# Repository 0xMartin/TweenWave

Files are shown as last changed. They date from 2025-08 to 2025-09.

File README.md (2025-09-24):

# TweenWave 🔌📡
#### GPIO Wi‑Fi + Sub‑GHz Module for Flipper Zero








A compact GPIO add‑on for Flipper Zero that combines 2.4 GHz Wi‑Fi and 433 MHz Sub‑GHz into one small board. Perfect for lab experiments, RF tinkering, and extending Flipper’s connectivity.

<table>
    <tr>
        <td align="center" width="50%">
            Real photo of TweenWave<br/>
            <sub>Actual TweenWave module (real photo)</sub>
        </td>
        <td align="center" width="50%">
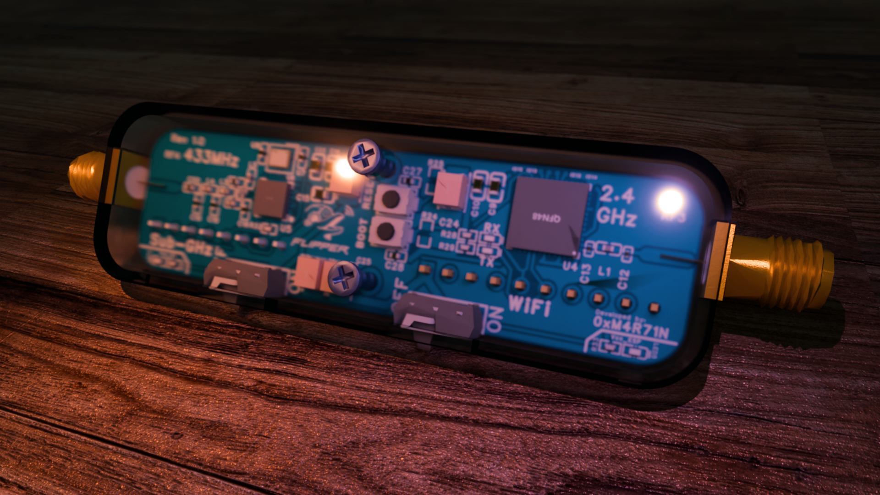
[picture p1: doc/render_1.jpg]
Render of TweenWave
            <br/>
            <sub>3D render of TweenWave (not a real photo)</sub>
        </td>
    </tr>
</table>

The module is designed to be as compact as possible, with replaceable antennas and the ability to remain permanently installed in the port.  
Two micro switches allow you to activate or deactivate the Wi‑Fi and Sub‑GHz radios, preventing unnecessary power draw when not in use.

> Photo of the TweenWave module plugged directly into the Flipper Zero GPIO port.  

Real photo of TweenWave<br/>

> **ℹ️ NOTE ℹ️** 
>
> Gerber files, Bill of Materials (BOM), and Pick and Place data for manufacturing the GPIO Wi‑Fi + Sub‑GHz Module for Flipper Zero are located in the [./export](./export) directory of this repository.

---

## Highlights

- 🧩 Direct plug‑in to Flipper Zero GPIO
- 📶 Wi‑Fi 2.4 GHz via ESP32‑PICO‑V3‑02  
    - Compatible with ESP32 Marauder firmware
- 📻 Sub‑GHz 433 MHz via TI CC1101
- 📡 External antennas using 2× SMA female connectors (one for Wi‑Fi, one for 433 MHz)
- 🧱 Small footprint, careful RF layout
- 🔄 ESP32 firmware updatable over UART (USB‑TTL)

---

## Specifications

- Radios
    - Wi‑Fi: 2.4 GHz (ESP32‑PICO‑V3‑02)
    - Sub‑GHz: 433 MHz (TI CC1101)
- Antennas: 2× SMA female (Wi‑Fi + 433 MHz)
- Power: from Flipper GPIO (3V3, GND)
- Interfaces
    - ESP32: UART/Serial from Flipper GPIO (for control/logs), flashing via external USB‑TTL
    - CC1101: SPI bus (see schematic)
- Indicators: status/power LEDs as routed on PCB
- Compatibility: Flipper Zero with GPIO header

Note: exact pin mapping and signals are shown in the schematic below.

---

## Quick Start

1. Attach suitable antennas:
     - 2.4 GHz antenna to the Wi‑Fi SMA
     - 433 MHz antenna to the Sub‑GHz SMA
2. Plug the module onto GPIO
3. Enable the Wi‑Fi or Sub‑GHz power switch on the module
4. Use Flipper’s serial/terminal to interact with ESP32 or integrate the CC1101 into your Sub‑GHz workflows

---

## ESP32 Marauder (short guide)

The firmware for this module is located in the `Firmware` directory of this repository. It is a fixed version of Marauder 1.8.6, modified to compile and upload for the ESP32-PICO-V3-02 chip used in this device. The project uses PlatformIO for building and flashing.

Precompiled `.bin` files are available in the repository releases as `MARAUDER_v1.8.6_ESP32_PICO_V3_02.zip`. The release contains:
- `bootloader.bin`
- `firmware.bin`
- `firmware.elf`
- `partitions.bin`

### Flashing precompiled binaries

1. Connect your ESP32-PICO-V3-02 module via USB-TTL to your computer.
2. Use [esptool.py](https://github.com/espressif/esptool) or similar tool to flash the binaries:
    ```sh
    esptool.py --chip esp32 --port /dev/ttyUSB0 --baud 460800 write_flash -z 0x1000 bootloader.bin 0x8000 partitions.bin 0x10000 firmware.bin
    ```
    Adjust the serial port as needed.

### Building and flashing with PlatformIO

1. Install [PlatformIO](https://platformio.org/) (VS Code extension or CLI).
2. Open the `Firmware` folder in PlatformIO.
3. Select the correct environment for ESP32-PICO-V3-02.
4. Click "Build" to compile the firmware.
5. Click "Upload" to flash directly to the chip.

For more details, see the PlatformIO documentation or the Marauder firmware README.

---

## Technical Views

<p align="center">
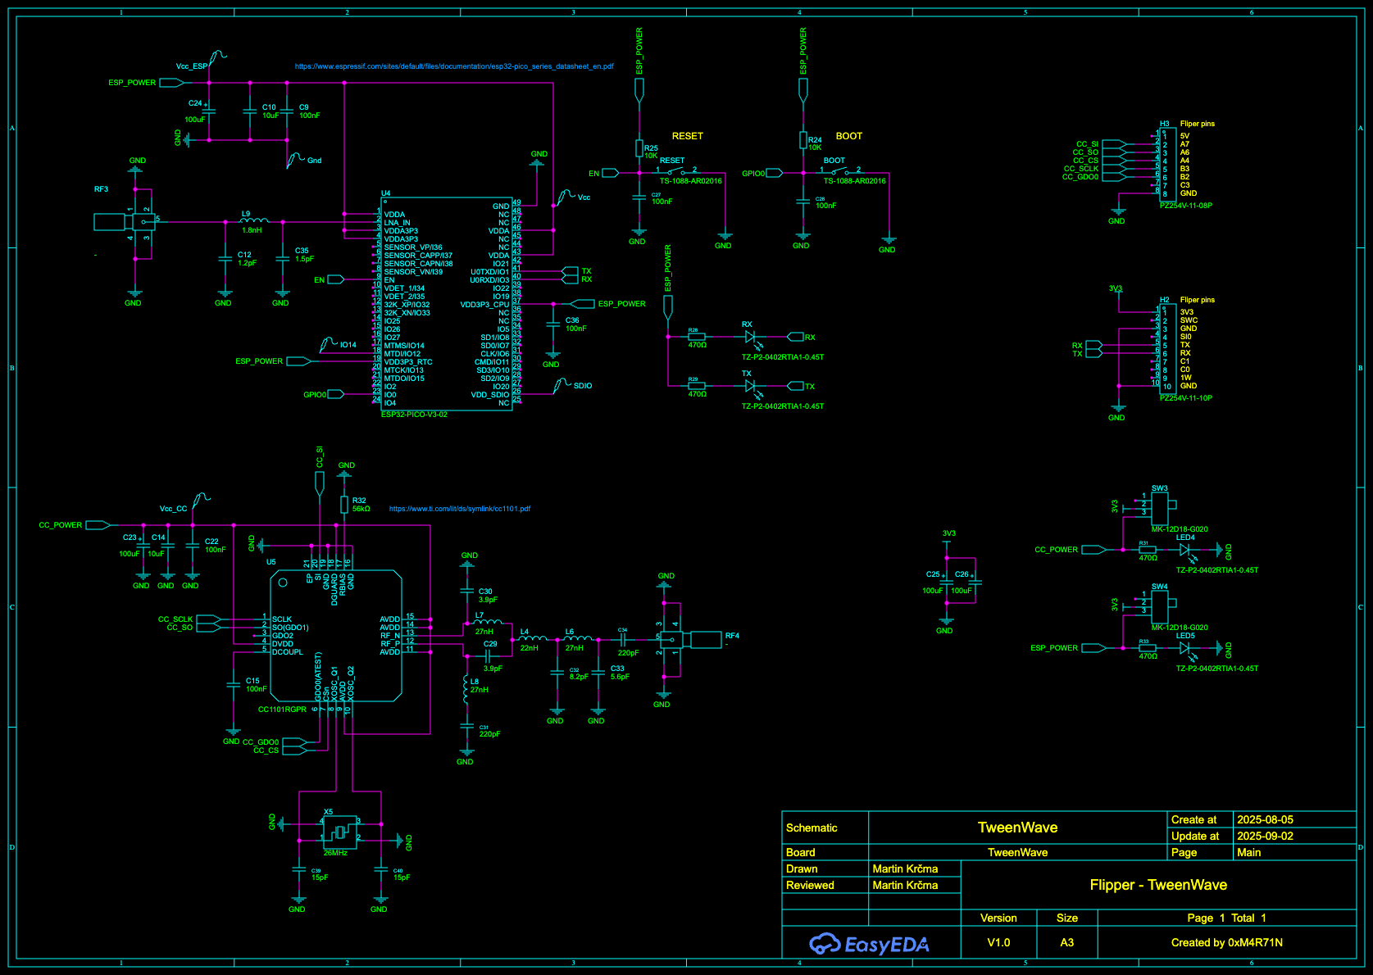
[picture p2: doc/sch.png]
Schematic
    
</p>

<p align="center">
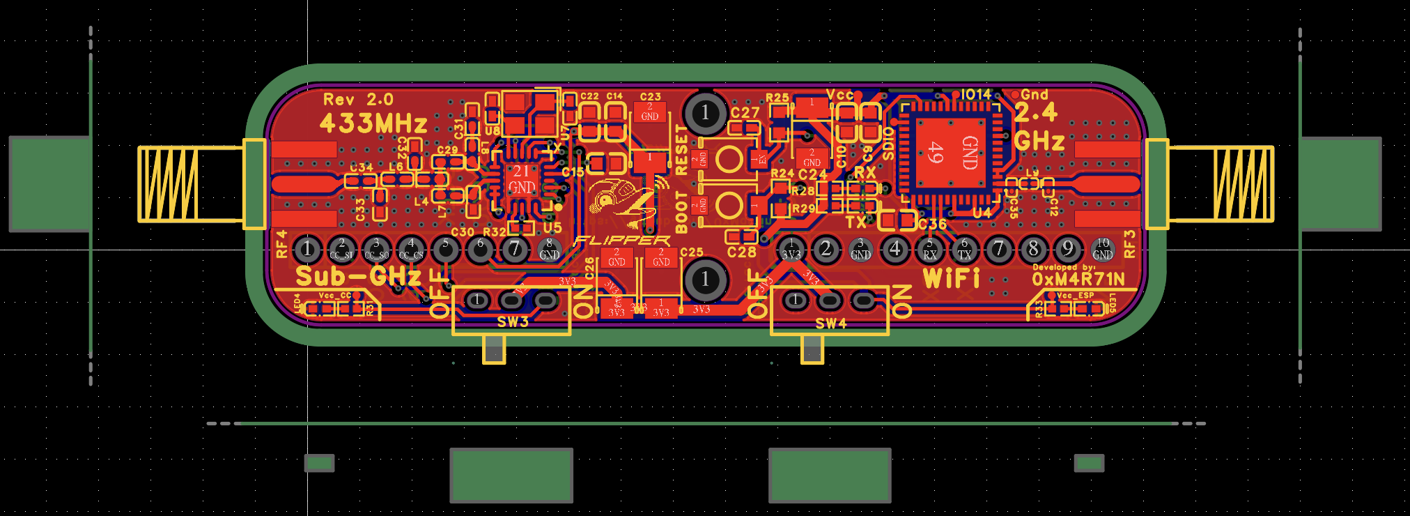
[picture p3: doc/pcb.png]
PCB – top view
    
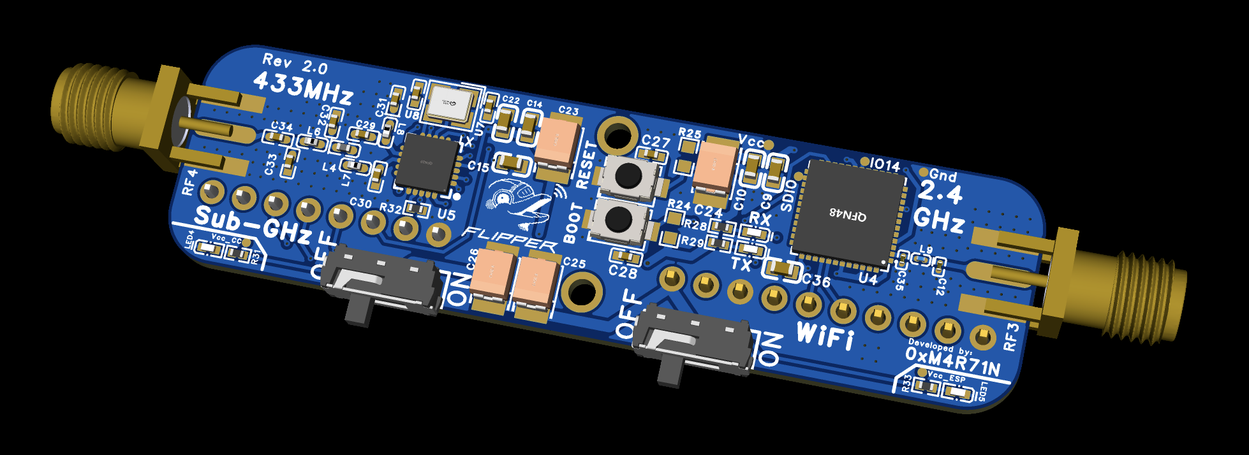
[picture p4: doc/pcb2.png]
PCB – 3D/side view
    
</p>

---

## RF, Safety, and Compliance

- Use properly tuned antennas for 2.4 GHz and 433 MHz.
- Do not transmit without an antenna connected to avoid RF stage damage.
- Observe local regulations and duty‑cycle/ERP limits for ISM bands.
- Regulatory status: not certified. For lab/experimental use only. User is responsible for legal compliance and safe operation.
- Do not use in life‑support, safety‑critical, or mission‑critical systems.

---

## FAQ

- Does it support Marauder?  
    Yes. The ESP32‑PICO‑V3‑02 is wired for ESP32 Marauder support.

- Is CC1101 fixed to 433 MHz only?  
    The design and matching are optimized for 433 MHz. CC1101 can target other sub‑GHz bands, but follow the schematic/matching network and your local regulations.

- Where is the pinout?  
    See the schematic (doc/sch.png).

---

## Part list

| Comment | Designator | Footprint | JLCPCB Part # |
|---|---|---|---|
| 15pF | C39, C40 | C0402 | C106997 |
| 8.2pF | C32 | C0402 | C327205 |
| 56kΩ | R32 | R0402 | C25796 |
| TS-1088-AR02016 | BOOT, RESET | SW-SMD_L3.9-W3.0-P4.45 | C720477 |
| 220pF | C31, C34 | C0402 | C107001 |
| 22nH | L4 | L0402 | C12670 |
| 10K | R24, R25 | R0603 | C137819 |
| 26MHz | X5 | CRYSTAL-SMD_4P-L3.2-W2.5-BL | C15192 |
| 1.2pF | C12 | C0201 | C85895 |
| 100uF | C23, C24, C25, C26 | CASE-B_3528 | C16133 |
| 1.5pF | C35 | C0201 | C161414 |
| - | RF3, RF4 | SMA-SMD_BWSMA-KE-P001 | C496550 |
| 470Ω | R28, R29, R31, R33 | R0402 | C25117 |
| 5.6pF | C33 | C0402 | C505468 |
| 27nH | L6, L7, L8 | L0402-RD | C12669 |
| 100nF | C9, C15, C22, C36 | C0603 | C14663 |
| CC1101RGPR | U5 | QFN-20_L4.0-W4.0-P0.5-TL-EP | C29953 |
| 100nF | C27, C28 | C0402 | C60474 |
| ESP32-PICO-V3-02 | U4 | QFN-48_L7.0-W7.0-P0.50-BL-EP5.1  | C908392 |
| MK-12D18-G020 | SW3, SW4 | SW-TH_MK-12D18-G040 | C3019727 |
| 10uF | C10, C14 | C0603 | C85713 |
| 1.8nH | L9 | L0201-RD | C98040 |
| 3.9pF | C29, C30 | C0402 | C1566 |
| TZ-P2-0402RTIA1-0.45T | LED4, LED5, RX, TX | LED0402-RD_RED | C779449 |

## Author

- 0xM4R71N

---

## License and Disclaimer

Summary (non‑binding): personal, non‑commercial use only; no warranty; you are responsible for safe use and legal compliance.

Legal terms:

- License (Non‑Commercial, Personal, Attribution)
    - Copyright (c) 2025 Martin Krčma (0xM4R71N)
    - Permission is granted to use, view, and modify the hardware design files for personal, experimental, and non‑commercial purposes only.
    - Commercial manufacturing, distribution, or sale of the hardware, derivatives, or prebuilt devices is prohibited without prior written consent from the author.
    - When redistributing modified files for personal/non‑commercial use, retain this notice and attribute “0xM4R71N”.
- Warranty Disclaimer
    - The design, files, and documentation are provided “AS IS”, without warranties or conditions of any kind, express or implied, including but not limited to merchantability, fitness for a particular purpose, and non‑infringement.
- Limitation of Liability
    - To the maximum extent permitted by law, in no event shall the author or contributors be liable for any direct, indirect, incidental, special, exemplary, or consequential damages (including, but not limited to, loss of use, data, business, or profits; personal injury; property damage; or regulatory penalties) arising from or related to the use, misuse, or inability to use this design, even if advised of the possibility of such damages.
- User Responsibility and Compliance
    - You are solely responsible for evaluation, safe assembly, testing, operation, and compliance with applicable laws, regulations, and standards (including RF spectrum use and EMC).
    - Not intended for life‑support, safety‑critical, or high‑risk environments.
- Miscellaneous
    - This notice is not legal advice. For commercial licensing or special permissions, contact the author.
    - Trademarks (e.g., “Flipper Zero”, “ESP32”) belong to their respective owners and are used for identification only.

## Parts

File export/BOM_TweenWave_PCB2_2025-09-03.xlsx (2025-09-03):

No. | Quantity | Comment | Designator | Footprint | Value | Manufacturer Part | Manufacturer | Supplier Part | Supplier
1 | 2 | TS-1088-AR02016 | BOOT,RESET | SW-SMD_L3.9-W3.0-P4.45 |  | TS-1088-AR02016 | XUNPU(讯普) | C720477 | LCSC
2 | 4 | 100nF | C9,C15,C22,C36 | C0603 | 100nF | CC0603KRX7R9BB104 | YAGEO(国巨) | C14663 | LCSC
3 | 2 | 10uF | C10,C14 | C0603 | 10uF | CL10A106MP8NNNC | SAMSUNG(三星) | C85713 | LCSC
4 | 1 | 1.2pF | C12 | C0201 | 1.2pF | GRM0335C1H1R2BA01D | muRata(村田) | C85895 | LCSC
5 | 4 | 100uF | C23,C24,C25,C26 | CASE-B_3528 | 100uF | TAJB107K006RNJ | Kyocera AVX | C16133 | LCSC
6 | 2 | 100nF | C27,C28 | C0402 | 100nF | CC0402KRX7R7BB104 | YAGEO(国巨) | C60474 | LCSC
7 | 2 | 3.9pF | C29,C30 | C0402 | 3.9pF | 0402CG3R9C500NT | FH(风华) | C1566 | LCSC
8 | 2 | 220pF | C31,C34 | C0402 | 220pF | CC0402JRNPO9BN221 | YAGEO(国巨) | C107001 | LCSC
9 | 1 | 8.2pF | C32 | C0402 | 8.2pF | CC0402BRNPO9BN8R2 | YAGEO(国巨) | C327205 | LCSC
10 | 1 | 5.6pF | C33 | C0402 | 5.6pF | CC0402BRNPO9BN5R6 | YAGEO(国巨) | C505468 | LCSC
11 | 1 | 1.5pF | C35 | C0201 | 1.5pF | GRM0335C1H1R5BA01D | muRata(村田) | C161414 | LCSC
12 | 2 | 15pF | C39,C40 | C0402 | 15pF | CC0402JRNPO9BN150 | YAGEO(国巨) | C106997 | LCSC
13 | 6 | Test-Point | Gnd,IO14,SDIO,Vcc,Vcc_CC,Vcc_ESP | Test-Point-0.5mm
14 | 1 | PZ254V-11-10P | H2 | HDR-TH_10P-P2.54-V-M |  | PZ254V-11-10P | XFCN(兴飞) | C492409 | LCSC
15 | 1 | PZ254V-11-08P | H3 | HDR-TH_8P-P2.54-V-M |  | PZ254V-11-08P | XFCN(兴飞) | C492407 | LCSC
16 | 1 | 22nH | L4 | L0402 | 22nH | LQG15HS22NJ02D | muRata(村田) | C12670 | LCSC
17 | 3 | 27nH | L6,L7,L8 | L0402-RD | 27nH | LQG15HS27NJ02D | muRata(村田) | C12669 | LCSC
18 | 1 | 1.8nH | L9 | L0201-RD | 1.8nH | LQP03TN1N8B02D | muRata(村田) | C98040 | LCSC
19 | 4 | TZ-P2-0402RTIA1-0.45T | LED4,LED5,RX,TX | LED0402-RD_RED |  | TZ-P2-0402RTIA1-0.45T | TUOZHAN(拓展光电) | C779449 | LCSC
20 | 2 | 10K | R24,R25 | R0603 |  | RC0603DR-0710KL | YAGEO(国巨) | C137819 | LCSC
21 | 4 | 470Ω | R28,R29,R31,R33 | R0402 | 470Ω | 0402WGF4700TCE | UNI-ROYAL(厚声) | C25117 | LCSC
22 | 1 | 56kΩ | R32 | R0402 | 56kΩ | 0402WGF5602TCE | UNI-ROYAL(厚声) | C25796 | LCSC
23 | 2 | - | RF3,RF4 | SMA-SMD_BWSMA-KE-P001 | - | BWSMA-KE-P001 | BAT WIRELESS(蝙蝠无线) | C496550 | LCSC
24 | 2 | MK-12D18-G020 | SW3,SW4 | SW-TH_MK-12D18-G040 |  | MK-12D18-G020 | G-Switch(品赞) | C3019727 | LCSC
25 | 1 | ESP32-PICO-V3-02 | U4 | QFN-48_L7.0-W7.0-P0.50-BL-EP5.1 |  | ESP32-PICO-V3-02 | ESPRESSIF(乐鑫) | C908392 | LCSC
26 | 1 | CC1101RGPR | U5 | QFN-20_L4.0-W4.0-P0.5-TL-EP |  | CC1101RGPR | TI(德州仪器) | C29953 | LCSC
27 | 1 | 26MHz | X5 | CRYSTAL-SMD_4P-L3.2-W2.5-BL | 26MHz | X322526MMB4SI | YXC(扬兴晶振) | C15192 | LCSC

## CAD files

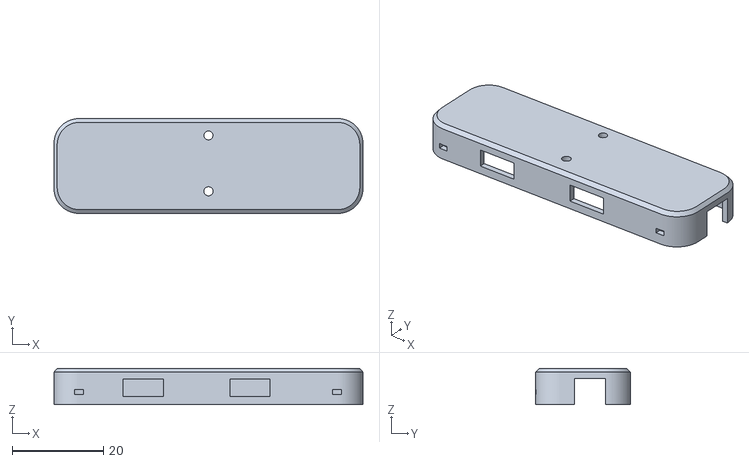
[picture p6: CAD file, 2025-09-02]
case/3DShell_3DShell_PCB2_T.stl
67.7 x 20.8 x 7.97

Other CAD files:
case/tween_wave.blend

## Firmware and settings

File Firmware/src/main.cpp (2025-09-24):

#include "configs.h"

#ifndef HAS_SCREEN
#define MenuFunctions_h
#define Display_h
#endif

#include "EvilPortal.h"
#include "esp_system.h"
#include "esp_wifi.h"
#include "esp_wifi_types.h"
#include "freertos/FreeRTOS.h"
#include "freertos/task.h"
#include <Arduino.h>
#include <WiFi.h>
#include <Wire.h>
#include <stdio.h>

#include "Assets.h"
#include "WiFiScan.h"
#include "Buffer.h"

#include "CommandLine.h"
#include "settings.h"

WiFiScan wifi_scan_obj;
EvilPortal evil_portal_obj;
Buffer buffer_obj;
Settings settings_obj;
CommandLine cli_obj;

const String PROGMEM version_number = MARAUDER_VERSION;

uint32_t currentTime = 0;

void setup()
{
#ifndef HAS_DUAL_BAND
    esp_spiram_init();
#endif

    Serial.begin(115200);

    while (!Serial)
        delay(10);

    Serial.println("ESP-IDF version is: " + String(esp_get_idf_version()));

    settings_obj.begin();
    buffer_obj = Buffer();

    wifi_scan_obj.RunSetup();
    evil_portal_obj.setup();
    wifi_scan_obj.StartScan(WIFI_SCAN_OFF);

    Serial.println(F("CLI Ready"));
    cli_obj.RunSetup();
}

void loop()
{
    currentTime = millis();
    bool mini = false;

    // Update all of our objects
    cli_obj.main(currentTime);
    wifi_scan_obj.main(currentTime);

    // Save buffer to SD and/or serial
    buffer_obj.save();
    settings_obj.main(currentTime);

    delay(50);
}

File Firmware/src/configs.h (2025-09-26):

#ifndef configs_h
#define configs_h

#define POLISH_POTATO

//// BOARD TARGETS
// #define MARAUDER_M5STICKC
// #define MARAUDER_M5STICKCP2
// #define MARAUDER_MINI
// #define MARAUDER_V4
// #define MARAUDER_V6
// #define MARAUDER_V6_1
// #define MARAUDER_V7
// #define MARAUDER_V7_1
// #define MARAUDER_KIT
#define GENERIC_ESP32
// #define MARAUDER_FLIPPER
// #define MARAUDER_MULTIBOARD_S3
// #define ESP32_LDDB
// #define MARAUDER_DEV_BOARD_PRO
// #define XIAO_ESP32_S3
// #define MARAUDER_REV_FEATHER
// #define MARAUDER_CYD_MICRO // 2432S028
// #define MARAUDER_CYD_2USB // Another 2432S028 but it has tWo UsBs OoOoOoO
// #define MARAUDER_CYD_GUITION // ESP32-2432S024 GUITION
// #define MARAUDER_C5
// #define MARAUDER_CARDPUTER
//// END BOARD TARGETS

#define MARAUDER_VERSION "v1.8.6"

#define GRAPH_REFRESH 100

#define DUAL_BAND_CHANNELS 51

#define HAS_PSRAM

//// HARDWARE NAMES
#ifdef MARAUDER_M5STICKC
#define HARDWARE_NAME "M5Stick-C Plus"
#elif defined(MARAUDER_M5STICKCP2)
#define HARDWARE_NAME "M5Stick-C Plus2"
#elif defined(MARAUDER_CARDPUTER)
#define HARDWARE_NAME "M5 Cardputer"
#elif defined(MARAUDER_MINI)
#define HARDWARE_NAME "Marauder Mini"
#elif defined(MARAUDER_V7)
#define HARDWARE_NAME "Marauder v7"
#elif defined(MARAUDER_V7_1)
#define HARDWARE_NAME "Marauder v7.1"
#elif defined(MARAUDER_REV_FEATHER)
#define HARDWARE_NAME "Adafruit Feather ESP32-S2 Reverse TFT"
#elif defined(MARAUDER_V4)
#define HARDWARE_NAME "Marauder v4"
#elif defined(MARAUDER_V6)
#define HARDWARE_NAME "Marauder v6"
#elif defined(MARAUDER_V6_1)
#define HARDWARE_NAME "Marauder v6.1"
#elif defined(MARAUDER_CYD_MICRO)
#define HARDWARE_NAME "CYD 2432S028"
#elif defined(MARAUDER_CYD_2USB)
#define HARDWARE_NAME "CYD 2432S028 2USB"
#elif defined(MARAUDER_CYD_GUITION)
#define HARDWARE_NAME "CYD 2432S024 GUITION"
#elif defined(MARAUDER_KIT)
#define HARDWARE_NAME "Marauder Kit"
#elif defined(MARAUDER_FLIPPER)
#define HARDWARE_NAME "Flipper Zero Dev Board"
#elif defined(MARAUDER_MULTIBOARD_S3)
#define HARDWARE_NAME "Flipper Zero Multi Board S3"
#elif defined(ESP32_LDDB)
#define HARDWARE_NAME "ESP32 LDDB"
#elif defined(MARAUDER_DEV_BOARD_PRO)
#define HARDWARE_NAME "Flipper Zero Dev Board Pro"
#elif defined(XIAO_ESP32_S3)
#define HARDWARE_NAME "XIAO ESP32 S3"
#elif defined(MARAUDER_C5)
#define HARDWARE_NAME "ESP32-C5 DevKit"
#else
#define HARDWARE_NAME "ESP32"
#endif

//// END HARDWARE NAMES

//// BOARD FEATURES
#if defined(MARAUDER_M5STICKC) || defined(MARAUDER_M5STICKCP2)
// #define FLIPPER_ZERO_HAT
#define HAS_MINI_KB
#define HAS_BATTERY
#define HAS_BT
#define HAS_BUTTONS
// #define HAS_NEOPIXEL_LED
#define HAS_PWR_MGMT
#define HAS_SCREEN
#define HAS_MINI_SCREEN
#define HAS_SD
#define USE_SD
#define HAS_TEMP_SENSOR
#define HAS_GPS
#endif

#if defined(MARAUDER_CARDPUTER)
// #define FLIPPER_ZERO_HAT
#define HAS_MINI_KB
// #define HAS_BATTERY
#define HAS_BT
#define HAS_BUTTONS
// #define HAS_NEOPIXEL_LED
// #define HAS_PWR_MGMT
#define HAS_SCREEN
#define HAS_MINI_SCREEN
#define HAS_SD
#define USE_SD
#define HAS_TEMP_SENSOR
#define HAS_GPS
#endif

#ifdef MARAUDER_MINI
// #define FLIPPER_ZERO_HAT
// #define HAS_BATTERY
#define HAS_MINI_KB
#define HAS_BT
#define HAS_BUTTONS
#define HAS_NEOPIXEL_LED
// #define HAS_PWR_MGMT
#define HAS_SCREEN
#define HAS_MINI_SCREEN
#define HAS_SD
#define USE_SD
#define HAS_TEMP_SENSOR
#define HAS_GPS
#endif

#ifdef MARAUDER_V7
// #define FLIPPER_ZERO_HAT
#define HAS_MINI_KB
#define HAS_BATTERY
#define HAS_BT
#define HAS_BT_REMOTE
#define HAS_BUTTONS
#define HAS_NEOPIXEL_LED
// #define HAS_PWR_MGMT
#define HAS_SCREEN
#define HAS_FULL_SCREEN
#define HAS_SD
#define USE_SD
#define HAS_TEMP_SENSOR
#define HAS_GPS
#endif

#ifdef MARAUDER_V7_1
// #define FLIPPER_ZERO_HAT
#define HAS_MINI_KB
#define HAS_BATTERY
#define HAS_BT
#define HAS_BT_REMOTE
#define HAS_BUTTONS
#define HAS_NEOPIXEL_LED
// #define HAS_PWR_MGMT
#define HAS_SCREEN
#define HAS_FULL_SCREEN
#define HAS_SD
#define USE_SD
#define HAS_TEMP_SENSOR
#define HAS_GPS
#define HAS_PSRAM
#endif

#ifdef MARAUDER_REV_FEATHER
// #define FLIPPER_ZERO_HAT
// #define HAS_BATTERY
// #define HAS_BT
#define HAS_MINI_KB
#define HAS_BUTTONS
#define HAS_NEOPIXEL_LED
// #define HAS_PWR_MGMT
#define HAS_SCREEN
#define HAS_MINI_SCREEN
#define HAS_SD
#define USE_SD
#define HAS_TEMP_SENSOR
#define HAS_GPS
#endif

#ifdef MARAUDER_V4
#define HAS_TOUCH
// #define FLIPPER_ZERO_HAT
#define HAS_BATTERY
#define HAS_BT
// #define HAS_BUTTONS
#define HAS_NEOPIXEL_LED
// #define HAS_PWR_MGMT
#define HAS_SCREEN
#define HAS_FULL_SCREEN
#define HAS_SD
#define USE_SD
#define HAS_TEMP_SENSOR
#define HAS_GPS
#endif

#if defined(MARAUDER_V6) || defined(MARAUDER_V6_1)
#define HAS_TOUCH
// #define FLIPPER_ZERO_HAT
#define HAS_BATTERY
#define HAS_BT
#define HAS_BT_REMOTE
#define HAS_BUTTONS
#define HAS_NEOPIXEL_LED
// #define HAS_PWR_MGMT
#define HAS_SCREEN
#define HAS_FULL_SCREEN
#define HAS_SD
#define USE_SD
#define HAS_TEMP_SENSOR
#define HAS_GPS
#endif
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

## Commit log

2025-08-10 pcb and sch update
2025-08-10 pcb update
2025-08-10 case update
2025-09-03 Update README with note on Gerber files and BOM
    Added note about manufacturing files location.
2025-09-27 firmware update
    [default_8M.csv]
